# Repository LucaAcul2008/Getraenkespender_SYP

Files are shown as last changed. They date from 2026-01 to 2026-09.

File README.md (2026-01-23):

# Getraenkespender_SYP
Automatisierter IoT-Getränkemischer auf Basis eines ESP32 (MicroPython) mit modernem React-Frontend zur Konfiguration. Steuert 6-12V-Membranpumpen für präzise Mischverhältnisse.

# 🍹 Smart Drink Mixer (ESP32 + React)

Ein vollautomatischer Getränkemischer, der zwei Flüssigkeiten über Membranpumpen in einem definierten Verhältnis mischt. Das System wird über physische Taster bedient und über ein responsives Web-Interface konfiguriert.

Dieses Projekt entstand als Projektarbeit in SYP.

## 🚀 Funktionen
* **Duale Pumpensteuerung:** Unabhängige Ansteuerung von zwei 6-12V-Membranpumpen (Selbstansaugend).
* **Web-Konfiguration:** Modernes React-Frontend (Single Page Application) zum Erstellen und Speichern von Getränke-Rezepten.
* **Hardware-Bedienung:** 3 physische Taster zum direkten Auslösen der gespeicherten Mischprofile.
* **Persistenz:** Speicherung der Konfigurationen im Flash-Speicher des ESP32 (JSON).
* **Custom Gehäuse:** Hybrid-Gehäuse aus 3D-Druck-Komponenten und Holz.

## 🛠 Technologie-Stack

### Hardware
* **Controller:** ESP32 (WLAN integriert)
* **Aktorik:** 2x 6-12V DC Membranpumpen 
* **Treiber:** MOSFET Schaltung (Logic Level) zur Ansteuerung der 6-12V Pumpen über 3.3V GPIOs
* **Stromversorgung:** 12V Netzteil + Step-Down Converter (für ESP32)

### Software
* **Firmware (Backend):** MicroPython
    * REST-API für die Kommunikation mit dem Frontend
    * Dateisystem-Management für Config-Dateien
* **Frontend (UI):** React.js
    * Responsive Design (Mobile First)
    * Kommunikation via `fetch` API

## 📂 Projektstruktur
```text
/firmware      -> MicroPython Code für den ESP32 (main.py, boot.py)
/frontend      -> Quellcode der React Web-App
/3d-models     -> STL-Dateien für Halterungen und Gehäuse
/docs          -> Schaltpläne und Dokumentation

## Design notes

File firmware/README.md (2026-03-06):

# Firmware — MicroPython ESP32

## Flash Instructions

### Prerequisites

| Tool | How to install |
|---|---|
| MicroPython on ESP32 | [https://micropython.org/download/ESP32_GENERIC/](https://micropython.org/download/ESP32_GENERIC/) (v1.21+ recommended) |
| Node.js + npm | [https://nodejs.org](https://nodejs.org) |
| mpremote | `pip install mpremote` |

### Quick start — automated script (recommended)

Connect the ESP32 via USB, then run from the **repository root**:

```bash
chmod +x flash.sh
./flash.sh
```

This single command will:
1. Build the React frontend (`npm install` + `npm run build`)
2. Upload `boot.py`, `main.py`, `config.json` to the ESP32
3. Create the `/www` directory on the ESP32 and upload the built frontend
4. Restart the ESP32

After flashing, connect to the WiFi hotspot and open the app (see [WiFi](#wifi) below).

### Manual steps (alternative)

1. Build the frontend:
```bash
cd frontend/getraenkespender
npm install
npm run build
```
This produces `frontend/getraenkespender/www/`.

2. Upload firmware files (from the repository root):
```bash
mpremote cp firmware/boot.py   :boot.py
mpremote cp firmware/main.py   :main.py
mpremote cp firmware/config.json :config.json
```

3. Upload the built frontend:
```bash
mpremote mkdir :www
# Upload all files from the www/ build output
find frontend/getraenkespender/www -type f | while read f; do
    remote=":www${f#frontend/getraenkespender/www}"
    mpremote cp "$f" "$remote"
done
```

4. Restart the ESP32:
```bash
mpremote reset
```

## GPIO Pin Assignment

| Function | GPIO |
|---|---|
| Pump A | 16 |
| Pump B | 17 |
| Button 1 (Recipe 1) | 4 |
| Button 2 (Recipe 2) | 5 |
| Button 3 (Recipe 3) | 6 |

## WiFi

- **Mode:** Access Point
- **SSID:** `GetraenkeBot_3000`
- **Password:** `party1234`
- **ESP32 IP:** `192.168.4.1`
- **App URL:** `http://192.168.4.1`

## API Endpoints

| Method | Path | Description |
|---|---|---|
| GET | /api/status | Returns `{"status": "ready"}` or `{"status": "busy"}` |
| GET | /api/config | Returns full config JSON |
| POST | /api/config | Save new config JSON |
| POST | /api/action | Trigger an action (see below) |

### Actions (`POST /api/action` with `{"command": "..."}`)

| Command | Effect |
|---|---|
| `start_pump_A` | Pump A ON (manual) |
| `stop_pump_A` | Pump A OFF |
| `start_pump_B` | Pump B ON (manual) |
| `stop_pump_B` | Pump B OFF |
| `flush_all` | Both pumps 15s each |
| `recipe_1` | Run Recipe 1 |
| `recipe_2` | Run Recipe 2 |
| `recipe_3` | Run Recipe 3 |

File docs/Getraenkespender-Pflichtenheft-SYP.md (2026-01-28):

**Pflichtenheft**

| **Projektname** | Getränkespender |
| --- | --- |
| **Projektnummer** | |
| **Projektleiter** | Raphael Thaler |
| **Erstellt am** | 09.01.2026 |
| **Letzte Änderung am** | 16.01.2026 |
| **Status** | In Bearbeitung |
| **Aktuelle Version** | 1.1 |

**Änderungsverlauf**

| **Nr.** | **Datum** | **Version** | **Geänderte Kapitel** | **Art der Änderung** | **Autor** |
| --- | --- | --- | --- | --- | --- |
| 1 | 09.01.2026 | 1.0 | Alle | Erstellung | Luca Aigner |
| 2 | 16.01.2026 | 1.1 | 5.3, 5.4, 6.2 | Erweiterung | Luca Aigner |
| 3 | 27.01.2026 | 1.1 | 4.4, 5.3.2 | Erweiterung/Änderung | Luca Aigner |

Inhalt

[**1** **Einleitung** 4](#_Toc220435320)

[**2** **Allgemeines** 4](#_Toc220435321)

[2.1 **Ziel und Zweck des Dokuments** 4](#_Toc220435322)

[2.2 **Ausgangssituation** 4](#_Toc220435323)

[2.3 **Projektbezug** 4](#_Toc220435324)

[2.4 **Abkürzungen** 4](#_Toc220435325)

[2.5 **Teams und Schnittstellen** 4](#_Toc220435326)

[**3** **Konzept** 5](#_Toc220435327)

[3.1 **Ziel(e) des Anbieters** 5](#_Toc220435328)

[3.2 **Ziel(e) und Nutzen des Anwenders** 5](#_Toc220435329)

[3.3 **Zielgruppe(n)** 5](#_Toc220435330)

[3.3.1 **Endanwender (Konsumenten / Partygäste)** Diese Gruppe nutzt das Gerät ausschließlich zur Getränkeentnahme. 5](#_Toc220435331)

[3.3.2 **Betreiber (Gastgeber / Administratoren)** Diese Gruppe ist für die Inbetriebnahme, Befüllung und Konfiguration der Mischverhältnisse zuständig. 6](#_Toc220435332)

[3.3.3 **Privatanwender (Haushalt / Eigenbedarf)** Diese Zielgruppe stellt eine Personalunion aus Betreiber und Endanwender dar. Das Gerät wird im privaten Wohnbereich dauerhaft oder temporär aufgestellt. 6](#_Toc220435333)

[4 **Funktionale Anforderungen** 6](#_Toc220435334)

[4.1 **Kernfunktionalitäten (Hardware & Steuerung)** 6](#_Toc220435335)

[4.2 **Web-Interface & Konfiguration (React App)** 7](#_Toc220435336)

[4.3 **Datenhaltung & Kommunikation** 7](#_Toc220435337)

[4.4 **Optionale Erweiterung:** Gamification-Modul (Stochastisches Belohnungssystem) Dieses Modul dient der Erhöhung der Benutzerinteraktion durch einen spielerischen Ansatz ("Slot-Machine-Effekt"). 7](#_Toc220435338)

[**5** **Nichtfunktionale Anforderungen** 8](#_Toc220435339)

[5.1 **Allgemeine Anforderungen** 8](#_Toc220435340)

[5.2 **Gesetzliche Anforderungen** 8](#_Toc220435341)

[5.3 **Technische Anforderungen** 8](#_Toc220435342)

[5.3.1 **Web:** 8](#_Toc220435343)

[5.3.2 **Hardware:** 8](#_Toc220435344)

[5.4 **Betriebliche Anforderungen** 8](#_Toc220435345)

[6 Rahmenbedingungen 8](#_Toc220435346)

[6.1 Zeitplan 8](#_Toc220435347)

[_6.2_ **Rahmenbedingungen: Technische Anforderungen (Entwicklungsumgebung)** 8](#_Toc220435348)

[6.3 Problemanalyse 10](#_Toc220435349)

[6.4 Qualität 10](#_Toc220435350)

[7 Liefer- und Abnahmebedingungen 10](#_Toc220435351)

[8 Anhang 10](#_Toc220435352)

# **Einleitung**

Das vorliegende Pflichtenheft enthält die an das zu entwickelnde Produkt gestellten funktionalen sowie nicht-funktionalen Anforderungen. Es dient als Basis für die Ausschreibung und Vertragsgestaltung und bildet somit die Vorgabe für die Angebotserstellung. Kommt es zwischen Auftragnehmer und Auftraggeber zu einem Vertragsabschluss, ist das bestehende Pflichtenheft rechtlich bindend. Alle zuvor zwischen Auftraggeber und Auftragnehmer getroffenen Absprachen verlieren in der Regel durch das Pflichtenheft ihre Gültigkeit - sofern hier nichts Gegenteiliges vermerkt ist. Mit den Anforderungen werden die Rahmenbedingungen für die Entwicklung festgelegt, die vom Auftragnehmer im Pflichtenheft detailliert ausgestaltet werden.

# **Allgemeines**

## **Ziel und Zweck des Dokuments**

Dieses Pflichtenheft beschreibt ein Projekt über einen Getränkespender.

## **Ausgangssituation**

Dieses Projekt wird in schulischen Verhältnissen durchgeführt von Raphael Thaler, Luca Aigner, Lukas Gutmann und Clemens Deutinger.

## **Projektbezug**

Das vorliegende Projekt ist ein unabhängiges Projekt.

## **Abkürzungen**

_CT01 ist CodingTeam01_

_DT01 ist DesignTeam01_

_HWT01 ist HardwareTeam01_

## **Teams und Schnittstellen**

| **Rolle(n)** | **Name** | **Telefon** | **E-Mail** | **Team** |
| --- | --- | --- | --- | --- |
| Projektleiter | Raphael Thaler | 9116967 | [Raphael.thaler@htl-saalfelden.at](mailto:Raphael.thaler@htl-saalfelden.at) | CT01 |
| Entwickler | Luca Aigner | 06601442142 | [Luca.aigner@htl-saalfelden.at](mailto:Luca.aigner@htl-saalfelden.at) | CT01 |
| 3D-Designer | Clemens Deutinger | 06601411251 | [Clemens.deutinger@htl-saalfenden.at](mailto:Clemens.deutinger@htl-saalfenden.at) | DT01 |
| Systemelektroniker | Lukas Gutmann | 066704043305 | [Lukas.gutmann@htl-saalfelden.at](mailto:Lukas.gutmann@htl-saalfelden.at) | HWT01 |

Die Kommunikation erfolgt größtenteils von Person zu Person aber auch über Teams. Enge Zusammenarbeit besteht zwischen dem DT01 und HWT01 aber auch zwischen Kommunikationen mit CT01.

# **Konzept**

## **Ziel(e) des Anbieters**

Nachweis technischer Kompetenz (Proof of Concept): Es soll demonstriert werden, dass eine nahtlose Integration von Embedded Systems (ESP32/MicroPython) und modernen Web-Technologien (React) realisierbar ist. Ziel ist die Schaffung einer stabilen Kommunikationsschnittstelle (API) zwischen der Hardware-Steuerung und der Benutzeroberfläche.

Erstellung eines funktionsfähigen Prototyps (MVP): Ziel ist die Fertigstellung eines "Minimum Viable Product", das die Kernfunktionen (Pumpensteuerung, Konfiguration, Webserver) zuverlässig und reproduzierbar erfüllt. Der Prototyp soll als Basis für potenzielle spätere Erweiterungen (z.B. mehr Pumpen, Cloud-Anbindung) dienen.

Gewährleistung der Betriebssicherheit: Durch den Einsatz geeigneter Hardware-Komponenten (Gehäuse, MOSFET-Treiberstufen) und Software-Routinen soll ein sicherer Betrieb gewährleistet werden, bei dem Elektronik und Flüssigkeiten strikt getrennt sind, um Kurzschlüsse oder Fehlfunktionen zu vermeiden.

Benutzerfreundlichkeit (Usability) ohne Vorkenntnisse: Die einfache Bedienung mittels Knöpfe und eines Gefäßes. Die Funktion der Knöpfe werden mittels einem Papierlabel beschrieben.

## **Ziel(e) und Nutzen des Anwenders**

Gemütliche Zubereitung eines Mischgetränks durch einen Knopfdruck.

## **Zielgruppe(n)**

## **Endanwender (Konsumenten / Partygäste)** Diese Gruppe nutzt das Gerät ausschließlich zur Getränkeentnahme

**Charakteristika**: Technisch oft Laien; befinden sich in einem geselligen Umfeld (Party, Event); erwarten sofortige Ergebnisse ohne Einarbeitungszeit.

**Anforderungen an das Produkt:** Die Bedienung muss extrem simpel und selbsterklärend sein ("Walk-up-and-use"). Da diese Nutzer nur mit der Hardware (Gehäuse/Taster) interagieren, stehen Robustheit und klare Beschriftung (Papierschilder) im Vordergrund. Fehleingaben oder wildes Drücken der Tasten müssen softwareseitig abgefangen werden.  
<br/><br/><br/><br/>

## **Betreiber (Gastgeber / Administratoren)** Diese Gruppe ist für die Inbetriebnahme, Befüllung und Konfiguration der Mischverhältnisse zuständig

**Charakteristika:** Besitzen grundlegende Kenntnisse im Umgang mit Smartphones oder Laptops; sind verantwortlich für den reibungslosen Ablauf.

**Anforderungen an das Produkt:** Sie benötigen Zugriff auf die Konfigurationsebene (React-Webinterface). Für sie muss die Oberfläche übersichtlich gestaltet sein, um schnell Rezepte ändern zu können, ohne den Programmcode (MicroPython) verstehen oder bearbeiten zu müssen. Eine mobile Optimierung der Webseite ist für diese Gruppe essenziell, da die Konfiguration vermutlich spontan über das Smartphone erfolgt.

## **Privatanwender (Haushalt / Eigenbedarf)** Diese Zielgruppe stellt eine Personalunion aus Betreiber und Endanwender dar. Das Gerät wird im privaten Wohnbereich dauerhaft oder temporär aufgestellt

**Charakteristika:** Der Nutzer konfiguriert das Gerät nach seinen persönlichen Vorlieben und nutzt es anschließend selbst für den täglichen Bedarf oder im familiären Rahmen. Die Frequenz der Nutzung ist geringer als im Party-Betrieb, dafür erfolgt der Einsatz über einen längeren Zeitraum.

**Anforderungen an das Produkt:** Hier stehen **Komfort** und **Wartungsfreundlichkeit** im Fokus. Da der Nutzer auch für die Reinigung zuständig ist, muss der Prozess des Durchspülens oder Wechselns der Flüssigkeiten möglichst einfach gestaltet sein. Zudem spielen Ästhetik und Platzbedarf eine größere Rolle, da das Gerät in den Wohnraum integriert wird. Die Geräuschentwicklung der Pumpen sollte auf ein wohnraumtaugliches Maß beschränkt sein.

# **Funktionale Anforderungen**

## **Kernfunktionalitäten (Hardware & Steuerung)**

- **/F010/ Zeitgesteuerte Pumpenansteuerung:** Das System muss in der Lage sein, zwei Gleichstrompumpen (Pumpe A und Pumpe B) unabhängig voneinander ein- und auszuschalten. Die Ansteuerung erfolgt zeitbasiert (Dauer in Sekunden/Millisekunden).
- **/F020/ Mischprofile abrufen:** Das System muss auf dem Mikrocontroller (ESP32) drei vordefinierte Profile ("Rezepte") vorhalten. Ein Profil besteht aus einem Datensatz, der die Laufzeit für Pumpe A und Pumpe B definiert.
- **/F030/ Physische Auslösung (Trigger):** Über drei Hardware-Taster am Gehäuse muss der Mischvorgang gestartet werden können.
  - Taster 1 löst Profil 1 aus.
  - Taster 2 löst Profil 2 aus.
  - Taster 3 löst Profil 3 aus.
- **/F040/ Blockierfunktion (Interlock):** Während ein Pumpvorgang läuft, müssen Eingaben über die anderen Taster ignoriert werden, um eine Doppel-Dosierung oder Fehler im Ablauf zu verhindern.
- **/F050/ Not-Abbruch:** Es muss eine Möglichkeit geben, einen laufenden Pumpvorgang sofort zu beenden (z.B. durch langes Drücken eines beliebigen Tasters oder einen dedizierten Reset), falls ein Glas überläuft.

## **Web-Interface & Konfiguration (React App)**

- **/F060/ Dashboard-Ansicht:** Die Web-Applikation muss den aktuellen Status des Systems anzeigen (z.B. "Bereit", "Mischt gerade", "Fehler").
- **/F070/ Rezept-Konfiguration:** Die Webseite muss ein Formular bereitstellen, mit dem die Laufzeiten für Pumpe A und Pumpe B für jeden der drei Taster (Slots) individuell eingestellt werden können.
  - Eingabeformat: Numerisch (z.B. in Sekunden).
- **/F080/ Validierung:** Die Eingaben müssen vor dem Senden validiert werden (z.B. keine negativen Zeiten, maximale Laufzeitbegrenzung zum Schutz der Pumpen).
- **/F090/ Manuelle Steuerung (Wartungsmodus):** Über das Web-Interface sollen die Pumpen manuell gestartet und gestoppt werden können (z.B. zum Ansaugen der Flüssigkeit nach Neubefüllung oder zur Reinigung), ohne einen automatischen Timer zu nutzen.

## **Datenhaltung & Kommunikation**

- **/F100/ Persistente Speicherung:** Änderungen an den Rezepten, die über das Web-Interface vorgenommen werden, müssen dauerhaft im Flash-Speicher des ESP32 gespeichert werden (z.B. als JSON-Datei). Die Einstellungen müssen nach einem Stromausfall wiederhergestellt werden.
- **/F110/ API-Schnittstelle:** Der ESP32 muss eine REST-API (oder vergleichbare Schnittstelle) bereitstellen, über die das React-Frontend die aktuellen Konfigurationen lesen (GET) und neue Konfigurationen schreiben (POST) kann.

## **Optionale Erweiterung:** Gamification-Modul (Stochastisches Belohnungssystem)  

Dieses Modul dient der Erhöhung der Benutzerinteraktion durch einen spielerischen Ansatz ("Slot-Machine-Effekt").

- /F_OPT_010/ Signalverarbeitung Münzeinwurf: Das System muss digitale Impulse eines externen Münzprüfers (Coin Acceptor) erfassen. Ein valider Einwurf wird als "Trigger-Event" gewertet, der das System aus dem Ruhezustand weckt.
- /F_OPT_020/ Physische Interaktion (Hebel/Trigger): Der Spielmechanismus wird über einen physischen Aktor (Hebelmechanik mit Mikroschalter oder Arcade-Button) gestartet.
  - Sperre: Der Hebel ist standardmäßig softwareseitig deaktiviert. Betätigungen ohne vorherigen Münzeinwurf werden ignoriert (ggf. mit visueller Fehlermeldung).
  - Freigabe: Erst nach registriertem Münzeinwurf wird der Hebel für genau einen Spielzyklus freigegeben.
- /F_OPT_030/ Lokale Visualisierung (Display): Das Gerät verfügt über ein integriertes Display zur direkten Nutzerführung am Gerät, unabhängig vom Web-Interface.
  - Idle-State: Anzeige einer Aufforderung (z.B. "Münze einwerfen").
  - Game-State: Nach Betätigung des Hebels visualisiert das Display den Zufallsprozess (z.B. durchlaufende Symbole).
  - Result-State: Anzeige von "Gewinn" (Auslösen der Pumpen) oder "Niete".
- /F_OPT_040/ Zufallsalgorithmus (RNG): Der Mikrocontroller führt eine Zufallsberechnung durch. Die Gewinnwahrscheinlichkeit (z.B. 1:10) ist variabel.
- /F_OPT_050/ Admin-Konfiguration (Web): Die Konfiguration der Gewinnwahrscheinlichkeit und des ausgegebenen "Gewinn-Getränks" erfolgt ausschließlich über einen geschützten Bereich im React-Webinterface (Admin-Panel), auf den normale Endanwender keinen Zugriff haben.

# **Nichtfunktionale Anforderungen**

## **Allgemeine Anforderungen**

**/NF010/ Leistung & Reaktionszeit (Latenz)** Da das System physische Flüssigkeiten bewegt, ist die wahrgenommene Reaktionszeit entscheidend.

- **Pumpenstart:** Zwischen dem Drücken eines physischen Tasters und dem Anlaufen der Pumpen darf maximal eine Verzögerung von **3 Sekunden** liegen.
- **Web-Interface:** Da der ESP32 als Webserver begrenzte Ressourcen hat, wird eine Ladezeit der Konfigurations-Webseite von unter **8 Sekunden** angestrebt. Speicher-Operationen (Speichern der Config) müssen innerhalb von **5 Sekunde** bestätigt werden.  
    <br/><br/><br/><br/>

**/NF020/ Sicherheit (Safety & Security)**

- **Elektrische Sicherheit:** Da Elektronik und Flüssigkeiten (leitfähig) in einem Gerät verbaut sind, müssen die flüssigkeitsführenden Teile (Schläuche/Pumpen) physisch von der Steuerelektronik (ESP32/PCB) getrennt sein (z.B. durch eine Trennwand im 3D-Druck-Gehäuse).
- **Eingabevalidierung:** Die Software muss verhindern, dass fehlerhafte Eingaben (z.B. negative Zahlen oder Text statt Zahlen) im Web-Interface zu einem Absturz des Mikrocontrollers führen.
- **Spannung:** Das System arbeitet im für den Menschen ungefährlichen Kleinspannungsbereich (max. 12V DC).

**/NF030/ Portabilität & Kompatibilität (Web)**

- **Plattformunabhängigkeit:** Das Web-Interface (React) muss auf den gängigen Browsern (Chrome, Safari, Firefox) lauffähig sein.
- **Responsive Design:** Da die Konfiguration vorwiegend "nebenbei" erfolgt, muss das Interface zwingend für **mobile Endgeräte (Smartphones)** optimiert sein (Touch-Bedienung, skalierbare Layouts).

**/NF040/ Verfügbarkeit & Robustheit**

- **Wi-Fi Reconnect:** Bei Verlust der WLAN-Verbindung muss der ESP32 versuchen, die Verbindung selbstständig wiederherzustellen, ohne dass ein manueller Neustart erforderlich ist.
- **Stand-Alone Betrieb:** Die Kernfunktion (Getränkeausgabe über Taster) muss auch dann funktionieren, wenn keine WLAN-Verbindung besteht oder das Web-Interface gerade nicht aufgerufen wird.

**/NF050/ Wartbarkeit & Modularität**

- **Code-Trennung:** Die Software-Architektur muss eine klare Trennung zwischen Backend (MicroPython Steuerlogik) und Frontend (React UI) aufweisen.
- **Austauschbarkeit:** Das Gehäuse-Design muss so gestaltet sein, dass Verschleißteile (Schläuche, Pumpenköpfe) zu Reinigungszwecken ohne Zerstörung des Gehäuses entnommen werden können.

## **Gesetzliche Anforderungen**

**Compliance & Sicherheit (Lebensmittel & Elektrik)**

- **Lebensmittelkonformität (LFGB / EU 1935/2004):** Alle Bauteile, die in direkten Kontakt mit den Getränken kommen (Schläuche, Pumpenmechanik, Düsen), müssen als "lebensmittelecht" (food grade) zertifiziert sein oder aus entsprechenden Materialien (z.B. Silikon, PETG, Edelstahl) bestehen.

## **Technische Anforderungen**

## **Web:**

**Zielplattform (Client-Seite)** Da die Benutzeroberfläche als Web-Applikation realisiert wird, ist sie plattformunabhängig konzipiert. Die Unterstützung folgender Umgebungen muss gewährleistet sein:

- Betriebssysteme: Unabhängig (Windows, macOS, iOS, Android, Linux).
- Browser: Die Anwendung muss auf allen modernen, HTML5-fähigen Browsern lauffähig sein (Google Chrome, Mozilla Firefox, Apple Safari, Microsoft Edge). Die Unterstützung des veralteten Internet Explorers ist nicht vorgesehen.
- Mobile Endgeräte: Prioritäre Unterstützung von Smartphones und Tablets (iOS und Android) im Hochformat (Portrait-Mode), da dies das primäre Konfigurationswerkzeug für den "Betreiber" darstellt.

**Designvorgaben & User Interface (UI)**

- Mobile First & Responsive Design: Die React-Oberfläche muss sich dynamisch an die Bildschirmgröße anpassen. Auf kleinen Bildschirmen (Smartphones) werden Elemente untereinander angeordnet (Stacking), auf größeren Bildschirmen (Laptops) nebeneinander.
- Touch-Optimierung: Alle interaktiven Elemente (Buttons, Slider, Eingabefelder) müssen groß genug dimensioniert sein, um fehlerfrei mit dem Finger bedient werden zu können (Mindestgröße von Touch-Targets ca. 44x44 Pixel).
- Corporate Design / Styling: Das Design soll modern und minimalistisch gehalten werden. Es wird ein dunkles Farbschema ("Dark Mode") bevorzugt, da das Gerät voraussichtlich in abgedunkelten Umgebungen (Partys) eingesetzt wird und dies die Blendwirkung reduziert.

Barrierefreiheit (Accessibility) Die Software orientiert sich an grundlegenden Prinzipien der Barrierefreiheit, um die Bedienung auch unter erschwerten Bedingungen (schlechte Beleuchtung, eingeschränkte Motorik) zu ermöglichen:

- Skalierbarkeit: Texte müssen über die Browser-Einstellungen vergrößerbar sein, ohne das Layout zu zerstören.
- Kontraste: Es ist auf einen ausreichenden Kontrast zwischen Text und Hintergrund zu achten, um die Lesbarkeit in dunklen Räumen zu gewährleisten.
- Visuelles Feedback: Interaktionen (z.B. Speichern der Konfiguration) müssen durch eindeutige visuelle Rückmeldungen (Ladebalken, Farbwechsel, "Toast"-Nachrichten) bestätigt werden, damit der Nutzer nicht auf Audio-Feedback angewiesen ist.

## **Hardware:**

**Recheneinheit (Mikrocontroller)**

- **Komponente:** ESP32 SoC (System on a Chip).
- **Anforderung:** Der Controller muss über integriertes WLAN (2.4 GHz) verfügen, um den Webserver bereitstellen zu können.
- **Speicher:** Ausreichend Flash-Speicher (min. 4MB) für die MicroPython-Firmware, die React-Web-Applikation und die Konfigurationsdateien.
- **I/O-Schnittstellen:** Es werden mindestens 5 GPIOs benötigt (2x Output für Pumpen, 3x Input für Taster).

**Aktorik & Fluidik**

- **Pumpen:** Einsatz von zwei selbstansaugenden Membranpumpen (6V-12V).
  - _Anforderung:_ Die Pumpen müssen lebensmittelecht sein und eine Saughöhe aufweisen, die es erlaubt, Flüssigkeiten aus unterhalb stehenden Behältern zu fördern (Self-priming).
- **Leistungselektronik (Treiberstufe):**
  - Da der Mikrocontroller (3.3V) die Pumpen (6V) nicht direkt treiben kann, ist eine Treiberstufe erforderlich.
  - _Anforderung:_ Einsatz von MOSFETs (z.B. IRLZ44N oder Module), um die galvanische Trennung und Leistungsverstärkung sicherzustellen.

**Stromversorgung**

- **Spannungsquelle:** Externes Netzteil (9V DC), welches genügend Strom (min. 2A) liefert, um beide Pumpen simultan sowie den Controller zu versorgen.
- **Spannungswandlung:** Integration eines Step-Down-Converters (Buck Converter) zur effizienten Wandlung von 9V auf 5V/3.3V für den ESP32.
- **Spannungswandlung (Peripherie):** Falls Komponenten mit 12V-Bedarf (z.B. Standard-Münzprüfer) eingesetzt werden, ist der Einsatz eines Step-Up-Converters (Boost Converter) von 9V auf 12V vorzusehen.

**Gehäuse & Physischer Aufbau**

- **Material:** Hybrid-Konstruktion aus 3D-Druck-Komponenten (für Halterungen und Passgenauigkeit) und Holz (für die Struktur/Optik).
- **Zwei-Kammer-System:** Konstruktive Trennung in einen "Nassbereich" (Schläuche, Auslassdüse) und einen "Trockenbereich" (ESP32, Netzteil, MOSFETs), um die Elektronik vor Leckagen zu schützen.

**Zusatz-Peripherie (Gamification)**

- **Display-Einheit:** OLED (z.B. SH1106/SSD1306) oder TFT Modul zur Statusanzeige direkt am Gehäuse.
- **Eingabe-Sensorik:** Mikroschalter (Microswitch) zur Erfassung der Hebel-Position (mechanischer Trigger).
- **Münzverarbeitung:** Elektronischer Münzprüfer mit 12V Puls-Signal.
  - **Interface:** Anbindung an den ESP32 über Pegelwandler oder Spannungsteiler (Level Shifter), um das 12V Signal auf verträgliche 3.3V zu skalieren.

## **Betriebliche Anforderungen**

**Deployment-Prozess (Software-Verteilung)** Da das System lokal und ohne Internetanbindung arbeitet, erfolgt das Deployment neuer Software-Versionen nicht über eine Cloud-Pipeline (CI/CD), sondern physisch am Gerät.

- **Firmware-Flash:** Das Aufspielen der MicroPython-Firmware und des React-Frontends (Build-Dateien) erfolgt über eine kabelgebundene USB-Verbindung (Serielle Schnittstelle) mittels geeigneter Tools (z.B. Thonny IDE, esptool).
- **Build-Pipeline:** Die React-Applikation muss vor dem Deployment lokal auf einem Entwickler-PC kompiliert ("build") und minifiziert werden, um den begrenzten Speicherplatz des ESP32 nicht zu überlasten.

**Hosting und Infrastruktur (On-Device Hosting)**

- **Self-Hosted:** Das System agiert vollständig autark ("On-Premises" / "On-Device"). Der ESP32 übernimmt die Rolle des Webservers und des Datenbank-Servers (Dateisystem). Es ist keine externe Server-Infrastruktur oder Cloud-Anbindung (AWS/Azure) erforderlich.
- **Netzwerk-Infrastruktur:** Das Gerät spannt entweder einen eigenen WLAN-Access-Point (AP-Mode) auf oder integriert sich in ein bestehendes lokales WLAN (Station-Mode).

**Backup und Wiederherstellung (Disaster Recovery)**

- **Konfigurations-Sicherheit:** Die vom Benutzer erstellten Rezepte (in der config.json) verbleiben im Flash-Speicher. Es ist kein automatisches Cloud-Backup vorgesehen.
- **Factory Reset:** Für den Fall einer fehlerhaften Konfiguration (z.B. WLAN-Passwort falsch eingegeben oder Endlosschleife im Code) muss eine Möglichkeit bestehen, das Gerät auf die Werkseinstellungen zurückzusetzen (z.B. durch Neu-Flashen via USB).
- **Quellcode-Sicherung:** Der Entwicklungsstand (Source Code) wird über ein Versionsverwaltungssystem (z.B. Git/GitHub) gesichert, um bei Datenverlust auf dem Entwickler-PC den Code wiederherstellen zu können.

**Wartung und Pflege (Maintenance)**

- **Software-Wartung:** Fehlerbehebungen (Bugfixes) oder Funktionserweiterungen erfordern den physischen Zugriff auf das Gerät (USB-Anschluss).
- **Hardware-Wartung (Hygiene):** Aufgrund des Lebensmittelkontakts müssen regelmäßige Wartungsintervalle für die Reinigung definiert werden (Durchspülen des Systems mit Wasser/Reinigungsmittel). Das System muss hierfür einen softwaregestützten Wartungsmodus ("Reinigungszyklus") bereitstellen, der beide Pumpen dauerhaft aktiviert.

# Rahmenbedingungen

_Hier gehen Sie zum Beispiel auf die gesamte Bearbeitungszeit ein. Beschreiben Sie ruhig auch die geplanten Betriebs- und Arbeitszeiten._

_Wird das Projekt nach einem bestimmen Entwicklungsprozess durchgeführt? (z.B.: V-modell, Wasserfallmodel, Agile, ...)_

## Zeitplan

_Wie viel Zeit wird für einzelne Phasen voraussichtlich aufgwendet? Hier sollte eine Übersicht folgen, die möglichst auch Arbeitszeiten oder ggf. Betriebspausen miteinbezieht._

## **Rahmenbedingungen: Technische Anforderungen (Entwicklungsumgebung)**

Für die Realisierung des Projekts werden folgende Technologien, Software-Stacks und Entwicklungswerkzeuge eingesetzt:

**Programmiersprachen und Technologien**

- **Frontend (Benutzeroberfläche):**
  - **Framework:** React.js (JavaScript/JSX) zur Erstellung einer dynamischen Single-Page-Application (SPA).
  - **Styling:** CSS3 (ggf. mit CSS-Frameworks oder Modulen) für das responsive Design.
  - **Build-Prozess:** Nutzung von Node.js und npm (Node Package Manager), um den React-Code in statische HTML/JS-Dateien zu kompilieren, die auf dem Mikrocontroller gehostet werden können.
- **Backend / Firmware (Steuerung):**
  - **Sprache:** MicroPython. Diese Sprache wurde gewählt, da sie eine schnelle Iteration ermöglicht und leistungsfähige Bibliotheken für die Hardware-Ansteuerung (GPIO, WLAN) sowie einfache Webserver-Funktionalitäten bietet.
  - **Kommunikation:** Datenaustausch zwischen Frontend und Backend erfolgt über **HTTP-Requests (REST-API)** im JSON-Format.

**Datenbankanforderungen (Datenhaltung)**

- **File-Based Storage:** Aufgrund der Ressourcenbeschränkung des ESP32 wird keine relationale Datenbank (wie MySQL) eingesetzt.
- **Format:** Die Speicherung der Konfigurationen (Rezepte, Pumpenlaufzeiten) erfolgt in strukturierten **JSON-Dateien** (config.json) direkt im nicht-flüchtigen Flash-Dateisystem (LittleFS/FAT) des ESP32.
- **Anforderung:** Das Dateisystem muss so implementiert sein, dass Lese- und Schreibzugriffe threadsicher erfolgen, um Datenkorruption bei gleichzeitigen Zugriffen (Web-Request vs. Taster-Druck) zu vermeiden.

**Systemintegration (Schnittstellen)**

- **Hardware-Integration:** Der ESP32 steuert die Peripherie nicht direkt, sondern über eine definierte GPIO-Schnittstelle.
  - _Ausgänge:_ PWM- oder Digitalsignale an die Gate-Treiber (MOSFETs) der Pumpen.
  - _Eingänge:_ Digitale Inputs mit Pull-Up-Widerständen für die Taster.
- **Netzwerk-Integration:** Das System integriert sich als Client in ein bestehendes WLAN (Station Mode) oder fungiert als Access Point. Es werden keine externen APIs (Wetterdaten, Social Media) eingebunden.

**Entwicklungsumgebung & Tools**

- **Code-Editoren (IDEs):**
  - **Visual Studio Code:** Hauptentwicklungsumgebung für die React-Webapplikation und Code-Verwaltung.
  - **Visual Studio Code / Pymakr Plugin & Python Plugin:** Zum Flashen der Firmware, Hochladen der Dateien auf den ESP32 und zum Debugging (REPL-Konsole).
- **Versionskontrolle:**
  - **Git & GitHub:** Zur Versionierung des Quellcodes und zur Zusammenarbeit im Team. Es werden separate Repositories oder Ordner für Frontend und Firmware geführt.
- **Schaltplan & Design:**
  - **Fritzing:** Zur Erstellung der Schaltpläne und Verkabelungsskizzen.
  - **CAD-Software (CREO):** Für das Design des 3D-gedruckten Gehäuses und der Pumpenhalterungen

## Problemanalyse

_Fassen Sie die wichtigsten Probleme zusammen, die Sie erwarten. Wichtig ist vor allem, dass Sie für die wahrscheinlichsten Probleme bereits einen Lösungsansatz formulieren, um später Zeit zu sparen. Machen Sie sich auch über unwahrscheinliche Probleme Gedanken._

## Qualität

_Welche Anforderungen stellen Sie an die Qualität? Beschreiben Sie auch, wie die Qualitätssicherung, -kontrolle und -abnahme aussieht._

z.B.:

_·_ **_Testanforderungen_**_: Vorgaben zu Unit-Tests, Integrationstests, Lasttests und Benutzerakzeptanztests._

_·_ **_Fehlerbehandlung_**_: Beschreibung der Anforderungen an die Protokollierung und den Umgang mit Fehlern (z.B. Logging, Benutzerwarnungen)._

_·_ **_Code-Standards_**_: Einhaltung von Coding Guidelines, Best Practices und Überprüfung des Codes durch Code Reviews._

# Liefer- und Abnahmebedingungen

_Hier wird festgehalten, in welchem Umfang und zu welchem Preis Sie an Ihren Kunden wann und wo liefern sollen._

_Witerhin wird hier spezifiziert, wann das Projekt als abgeschlossen gilt und wer definiert, ob die Qualität stimmt. Es sollte klar festgelegt werden, wer für die Abnahme verantwortlich ist._

# Anhang

_Alle weiteren Dokumente oder Zahlen und Fakten, die als Hintergrund zu dem Projekt dienen._

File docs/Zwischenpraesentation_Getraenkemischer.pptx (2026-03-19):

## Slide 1

GETRÄNKEMISCHER

Zwischenpräsentation — Projektstand März 2026

Projektteam

Raphael Thaler (PL)
Luca Aigner · Lukas Gutmann · Clemens Deutinger

HTL Saalfelden · SYP 2025/26

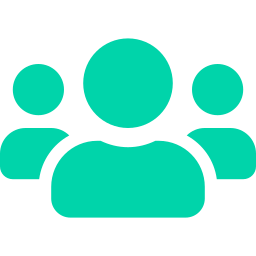
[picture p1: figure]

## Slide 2

AGENDA

Projektuebersicht

Was bauen wir?

01

Aktueller Projektstand

Was funktioniert bereits?

02

Verzögerungen & Risiken

Wo gibt es Probleme?

03

Meilensteintrendanalyse

Visualisierung der Trends

04

Nächste Schritte

Wie geht es weiter?

05

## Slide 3

PROJEKTÜBERSICHT

Was ist der Getränkemischer?

Ein automatisierter Getränkespender mit ESP32-Mikrocontroller, zwei Pumpen und einer React-Weboberfläche zur Konfiguration.

3 konfigurierbare Mischprofile

Physische Taster + Web-Interface

REST-API zwischen Frontend & ESP32

Dark-Mode UI, Mobile-First Design

Frontend

React.js + TypeScript + Vite

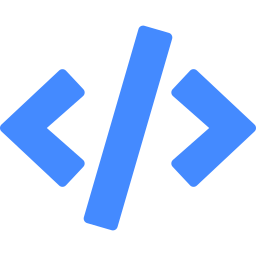
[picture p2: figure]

Backend

MicroPython auf ESP32

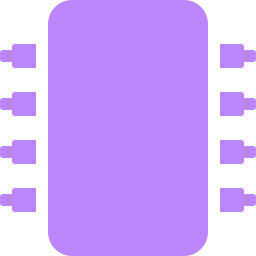
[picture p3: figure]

Hardware

3D-Druck + Holzgehäuse + Pumpen

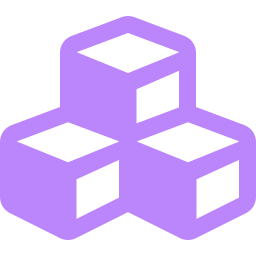
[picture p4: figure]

Kommunikation

REST-API (JSON über HTTP)

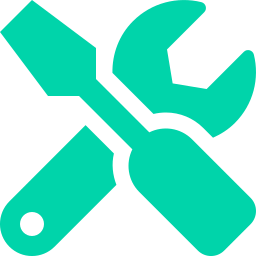
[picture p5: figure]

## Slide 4

AKTUELLER PROJEKTSTAND

Frontend (React)

Fertig

Login, Dashboard, Konfiguration, Navigation

Backend (ESP32)

Fertig

API, Pumpensteuerung, Webserver, Config

100%

100%

Designphase (CAD)

Verzögert

CAD-Design & 3D-Druck in Verzug

60%

Gehäusemontage

Verzögert

Abhängig von Designphase, Montage offen

40%

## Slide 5

VERZÖGERUNGEN & RISIKEN

Designphase (CAD & 3D-Druck)

Plan: 27.02.2026 → Aktuell: ca. 27.03.2026 (+4 Wochen)
Ursache: CAD-Modellierung komplexer als erwartet, 3D-Druck-Iterationen nötig
Auswirkung: Gehäusemontage und finaler Zusammenbau verzögern sich

KRITISCH

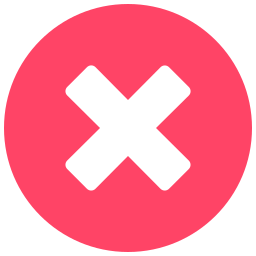
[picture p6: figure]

Gehäusemontage

Plan: 27.03.2026 → Aktuell: ca. 08.04.2026 (+12 Tage)
Blockiert durch Designphase — Montage kann erst nach Fertigstellung der 3D-Teile starten

WARNUNG

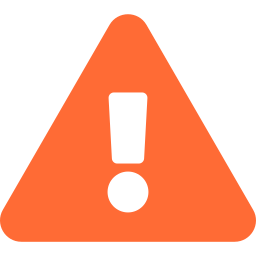
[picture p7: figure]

Frontend & Backend vorplanmäßig fertig — Software-Seite kein Risiko

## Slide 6

MEILENSTEINTRENDANALYSE

Trend der Meilenstein-Termine über die Berichtszeitraeume

Meilenstein | Plan | Aktuell | Delta | Trend
Designphase abgeschlossen | 27.02. | 27.03. | +4 Wochen | ↗ steigend
HW & Gehäuse montiert | 27.03. | 08.04. | +12 Tage | ↗ steigend
Backend & Elektronik | 10.04. | 27.03. | –2 Wochen | ↘ fallend
Frontend steuert HW | 17.04. | 20.03. | –4 Wochen | ↘ fallend
MVP funktionsfähig | 29.05. | 29.05. | ±0 | → stabil

Die Software-Meilensteine wurden vorzeitig erreicht und kompensieren teilweise die Hardware-Verzögerungen. Der MVP-Termin (29.05.) bleibt realistisch.

Interpretation:

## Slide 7

NÄCHSTE SCHRITTE

1

Designphase abschliessen

KW 13

CAD-Modelle finalisieren, 3D-Druck abschließen

Clemens (DT01)

2

Gehäusemontage & Verkabelung

KW 14–15

Gehäuse zusammenbauen, Elektronik integrieren

Lukas (HWT01)

3

Funktionstest (Trocken)

Software-Hardware-Integration prüfen

Luca + Raphael

KW 15

4

Wassertest & Kalibrierung

Dichtheit, Pumpen-Timing, Mengenmessung

Gesamtes Team

KW 16–20

5

Abschlusspraesentation

KW 25

Vorbereitung und Präsentation des fertigen MVP

Raphael (PL)

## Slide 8

DANKE!

Fragen & Diskussion

Raphael Thaler (PL) — raphael.thaler@htl-saalfelden.at
Luca Aigner — luca.aigner@htl-saalfelden.at
Lukas Gutmann — lukas.gutmann@htl-saalfelden.at
Clemens Deutinger — clemens.deutinger@htl-saalfelden.at

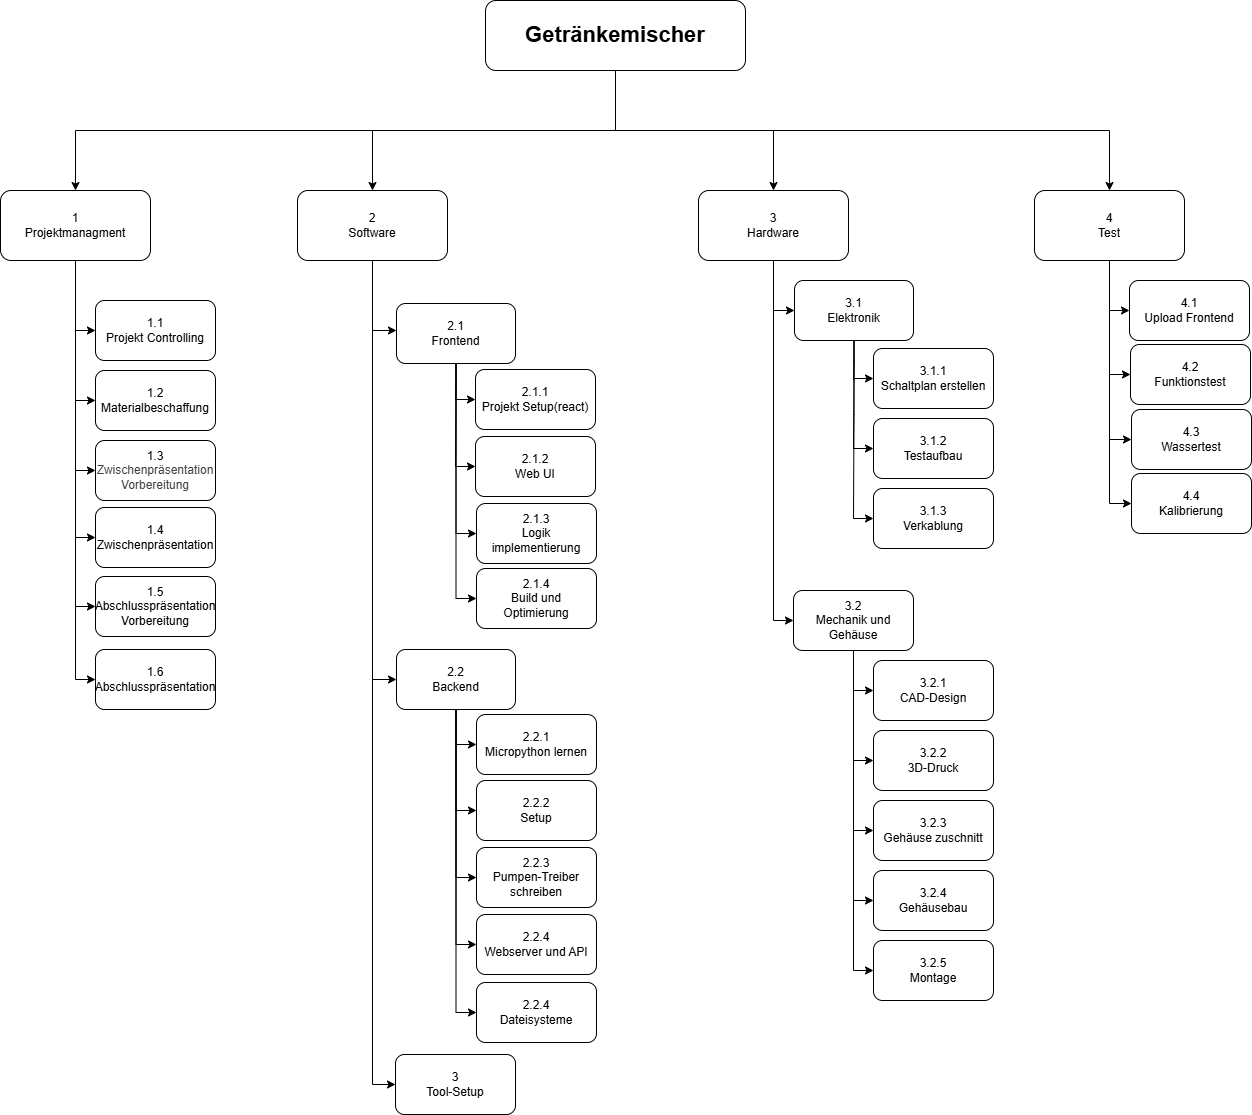
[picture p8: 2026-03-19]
docs/PSP_Syp 1.png

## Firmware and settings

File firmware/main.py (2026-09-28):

# firmware/main.py
import ujson
import uos
import machine
import time
import socket
import _thread

# --- Pin Setup ---
PUMP_A_PIN = machine.Pin(32, machine.Pin.OUT)
PUMP_B_PIN = machine.Pin(33, machine.Pin.OUT)
BTN_1_PIN  = machine.Pin(25, machine.Pin.IN, machine.Pin.PULL_UP)
BTN_2_PIN  = machine.Pin(26, machine.Pin.IN, machine.Pin.PULL_UP)
BTN_3_PIN  = machine.Pin(27, machine.Pin.IN, machine.Pin.PULL_UP)
LED_1_PIN  = machine.Pin(13, machine.Pin.OUT)
LED_2_PIN  = machine.Pin(16, machine.Pin.OUT)
LED_3_PIN  = machine.Pin(17, machine.Pin.OUT)

PUMP_A_PIN.value(0)
PUMP_B_PIN.value(0)
LED_1_PIN.value(0)
LED_2_PIN.value(0)
LED_3_PIN.value(0)

CONFIG_FILE = 'config.json'
is_busy      = False
emergency_stop = False
CONFIG_RELOAD_INTERVAL = 200

LEDS = [LED_1_PIN, LED_2_PIN, LED_3_PIN]

# --- Config Helpers ---
def load_config():
    try:
        with open(CONFIG_FILE, 'r') as f:
            return ujson.load(f)
    except:
        return {
            "recipes": [
                {"id": 1, "name": "Rezept 1", "pumpA": 5.0, "pumpB": 2.0},
                {"id": 2, "name": "Rezept 2", "pumpA": 3.0, "pumpB": 3.0},
                {"id": 3, "name": "Wasser",   "pumpA": 0.0, "pumpB": 5.0}
            ],
            "slotMachineChance": 10,
            "calibrationFactor": 5.0,
            "bottleA_ml": 1500,
            "bottleB_ml": 1500,
            "remainingA_ml": 1500,
            "remainingB_ml": 1500
        }

def save_config(cfg):
    with open(CONFIG_FILE, 'w') as f:
        ujson.dump(cfg, f)

def deduct_volume(pump_a_sec, pump_b_sec):
    cfg = load_config()
    cal = cfg.get('calibrationFactor', 5.0)
    ml_per_sec = 100.0 / cal if cal > 0 else 0
    cfg['remainingA_ml'] = max(0, cfg.get('remainingA_ml', 0) - pump_a_sec * ml_per_sec)
    cfg['remainingB_ml'] = max(0, cfg.get('remainingB_ml', 0) - pump_b_sec * ml_per_sec)
    save_config(cfg)
    return cfg['remainingA_ml'], cfg['remainingB_ml']

def is_bottle_empty(pump_a_sec, pump_b_sec):
    cfg = load_config()
    cal = cfg.get('calibrationFactor', 5.0)
    ml_per_sec = 100.0 / cal if cal > 0 else 0
    needed_a = pump_a_sec * ml_per_sec
    needed_b = pump_b_sec * ml_per_sec
    rem_a = cfg.get('remainingA_ml', 0)
    rem_b = cfg.get('remainingB_ml', 0)
    
    if pump_a_sec > 0 and rem_a < needed_a: return True, 'A'
    if pump_b_sec > 0 and rem_b < needed_b: return True, 'B'
    return False, None

# --- LED Helpers ---
def set_leds(a, b, c):
    LED_1_PIN.value(a)
    LED_2_PIN.value(b)
    LED_3_PIN.value(c)

def all_leds_off():
    set_leds(0, 0, 0)

def blink_all_leds_async(stop_flag):
    while not stop_flag[0]:
        set_leds(1, 1, 1)
        time.sleep(0.4)
        all_leds_off()
        time.sleep(0.4)
    all_leds_off()

# --- Pump Control ---
def emergency_stop_all():
    global is_busy, emergency_stop
    PUMP_A_PIN.value(0)
    PUMP_B_PIN.value(0)
    emergency_stop = True
    is_busy = False
    for _ in range(5):
        set_leds(1, 1, 1)
        time.sleep(0.1)
        all_leds_off()
        time.sleep(0.1)

def run_recipe(pump_a_sec, pump_b_sec, active_btn_led=None):
    global is_busy, emergency_stop
    if is_busy: return

    empty, _ = is_bottle_empty(pump_a_sec, pump_b_sec)
    if empty:
        for _ in range(10):
            set_leds(1, 1, 1)
            time.sleep(0.25)
            all_leds_off()
            time.sleep(0.25)
        return

    is_busy = True
    emergency_stop = False
    last_blink = time.ticks_ms()
    blink_on = False

    try:
        start = time.ticks_ms()
        if pump_a_sec > 0: PUMP_A_PIN.value(1)
        if pump_b_sec > 0: PUMP_B_PIN.value(1)

        a_done = pump_a_sec <= 0
        b_done = pump_b_sec <= 0

        while not (a_done and b_done):
            if emergency_stop: break
            elapsed = time.ticks_diff(time.ticks_ms(), start) / 1000.0
            if not a_done and elapsed >= pump_a_sec:
                PUMP_A_PIN.value(0)
                a_done = True
            if not b_done and elapsed >= pump_b_sec:
                PUMP_B_PIN.value(0)
                b_done = True
            if active_btn_led is not None:
                now = time.ticks_ms()
                if time.ticks_diff(now, last_blink) >= 300:
                    blink_on = not blink_on
                    active_btn_led.value(1 if blink_on else 0)
                    last_blink = now
            time.sleep(0.05)

        if not emergency_stop:
            deduct_volume(pump_a_sec, pump_b_sec)
            if active_btn_led is not None:
                active_btn_led.value(1)
                time.sleep(0.5)
    finally:
        PUMP_A_PIN.value(0)
        PUMP_B_PIN.value(0)
        if active_btn_led is not None:
            active_btn_led.value(0)
        is_busy = False

def run_recipe_async(pump_a_sec, pump_b_sec, active_btn_led=None):
    _thread.start_new_thread(run_recipe, (pump_a_sec, pump_b_sec, active_btn_led))

def run_flush():
    global is_busy, emergency_stop
    if is_busy: return
    is_busy = True
    emergency_stop = False
    try:
        start = time.ticks_ms()
        PUMP_A_PIN.value(1)
        PUMP_B_PIN.value(1)
        while time.ticks_diff(time.ticks_ms(), start) < 15000:
            if emergency_stop: break
            set_leds(1, 1, 1)
            time.sleep(0.3)
            all_leds_off()
            time.sleep(0.3)
    finally:
        PUMP_A_PIN.value(0)
        PUMP_B_PIN.value(0)
        all_leds_off()
        is_busy = False

# --- HTTP Server & Routing ---
CORS_HEADERS = 'Access-Control-Allow-Origin: *\r\nAccess-Control-Allow-Methods: GET, POST, OPTIONS\r\nAccess-Control-Allow-Headers: Content-Type\r\n'

def send_json(conn, data, status=200):
    body = ujson.dumps(data).encode()
    conn.send('HTTP/1.1 {} OK\r\nContent-Type: application/json\r\n{}Content-Length: {}\r\n\r\n'.format(
        status, CORS_HEADERS, len(body)).encode())
    conn.send(body)

def send_options(conn):
    conn.send('HTTP/1.1 204 No Content\r\n{}\r\n'.format(CORS_HEADERS).encode())

def read_body(request_text):
    try:
        parts = request_text.split('\r\n\r\n', 1)
        if len(parts) > 1: return parts[1].strip()
    except: pass
    return ''

def serve_file(conn, path):
    try:
        size = uos.stat(path)[6]
        ext = path.split('.')[-1]
        mime = {'html': 'text/html', 'js': 'application/javascript', 'css': 'text/css',
                'json': 'application/json', 'svg': 'image/svg+xml', 'ico': 'image/x-icon'}.get(ext, 'application/octet-stream')
        conn.send('HTTP/1.1 200 OK\r\nContent-Type: {}\r\nContent-Length: {}\r\n\r\n'.format(mime, size).encode())
        with open(path, 'rb') as f:
            while True:
                chunk = f.read(1024)
                if not chunk:
                    break
                conn.send(chunk)
    except OSError:
        conn.send(b'HTTP/1.1 404 Not Found\r\n\r\n404 Not Found')

def handle_request(conn):
    global is_busy, emergency_stop
    try:
        request = conn.recv(8192).decode('utf-8', 'ignore')
        lines = request.split('\r\n')
        if not lines or len(lines[0]) < 3: return
        
        method, path_full, *_ = lines[0].split(' ') + ['', '']
        path = path_full.split('?')[0]

        if method == 'OPTIONS':
            send_options(conn)
            return

        if path == '/api/status':
            cfg = load_config()
            send_json(conn, {
                'status': 'busy' if is_busy else 'ready',
                'remainingA_ml': cfg.get('remainingA_ml', 0),
                'remainingB_ml': cfg.get('remainingB_ml', 0),
                'bottleA_ml': cfg.get('bottleA_ml', 1500),
                'bottleB_ml': cfg.get('bottleB_ml', 1500)
            })

        elif path == '/api/config':
            if method == 'GET':
                send_json(conn, load_config())
            elif method == 'POST':
                body = read_body(request)
                try:
                    new_cfg = ujson.loads(body)
                    save_config(new_cfg)
                    send_json(conn, {'ok': True})
                except Exception as e:
                    send_json(conn, {'error': str(e)}, 400)

        elif path == '/api/refill':
            if method == 'POST':
                body = read_body(request)
                try:
                    data = ujson.loads(body)
                    cfg = load_config()
                    pump = data.get('pump', 'both')
                    if pump in ('A', 'both'): cfg['remainingA_ml'] = cfg.get('bottleA_ml', 1500)
                    if pump in ('B', 'both'): cfg['remainingB_ml'] = cfg.get('bottleB_ml', 1500)
                    save_config(cfg)
                    send_json(conn, {'ok': True, 'remainingA_ml': cfg['remainingA_ml'], 'remainingB_ml': cfg['remainingB_ml']})
                except Exception as e:
                    send_json(conn, {'error': str(e)}, 400)

        elif path == '/api/action':
            if method == 'POST':
                body = read_body(request)
                try:
                    data = ujson.loads(body)
                    cmd = data.get('command', '')
                except: cmd = ''

                if cmd == 'emergency_stop':
                    emergency_stop_all()
                    send_json(conn, {'ok': True})
                elif cmd == 'start_pump_A':
                    PUMP_A_PIN.value(1)
                    send_json(conn, {'ok': True})
                elif cmd == 'stop_pump_A':
                    PUMP_A_PIN.value(0)
                    send_json(conn, {'ok': True})
                elif cmd == 'start_pump_B':
                    PUMP_B_PIN.value(1)
                    send_json(conn, {'ok': True})
                elif cmd == 'stop_pump_B':
                    PUMP_B_PIN.value(0)
                    send_json(conn, {'ok': True})
                elif cmd == 'flush_all':
                    if not is_busy:
                        _thread.start_new_thread(run_flush, ())
                        send_json(conn, {'ok': True})
                    else:
                        send_json(conn, {'error': 'busy'}, 409)
                elif cmd.startswith('recipe_'):
                    try:
                        recipe_id = int(cmd.split('_')[1])
                        cfg = load_config()
                        recipe = next((r for r in cfg['recipes'] if r['id'] == recipe_id), None)
                        led = LEDS[recipe_id - 1] if 1 <= recipe_id <= 3 else None
                        if recipe and not is_busy:
                            run_recipe_async(recipe['pumpA'], recipe['pumpB'], led)
                            send_json(conn, {'ok': True})
                        elif is_busy:
                            send_json(conn, {'error': 'busy'}, 409)
                        else:
                            send_json(conn, {'error': 'recipe not found'}, 404)
                    except Exception as e:
                        send_json(conn, {'error': str(e)}, 400)
                else:
                    send_json(conn, {'error': 'unknown command'}, 400)

        elif path == '/' or path == '/index.html':
            serve_file(conn, '/www/index.html')
        else:
            serve_file(conn, '/www' + path)

    except Exception as e:
        print('Request error:', e)
    finally:
        conn.close()

def start_server():
    addr = socket.getaddrinfo('0.0.0.0', 80)[0][-1]
    s = socket.socket()
    s.setsockopt(socket.SOL_SOCKET, socket.SO_REUSEADDR, 1)
    s.bind(addr)
    s.listen(5)
    print('HTTP server running on port 80')
    while True:
        try:
            conn, addr = s.accept()
            handle_request(conn)
        except Exception as e:
            print('Server error:', e)

# --- Physical Button Polling ---
def poll_buttons():
    global is_busy, emergency_stop
    last_states   = [1, 1, 1]
    press_times   = [0, 0, 0]  
    btn1_tap_times = []        
    buttons = [BTN_1_PIN, BTN_2_PIN, BTN_3_PIN]
    leds    = [LED_1_PIN, LED_2_PIN, LED_3_PIN]
    cfg = load_config()
    cfg_reload_counter = 0

    while True:
        cfg_reload_counter += 1
        if cfg_reload_counter > CONFIG_RELOAD_INTERVAL:
            cfg = load_config()
            cfg_reload_counter = 0

        now = time.ticks_ms()
        states = [btn.value() for btn in buttons]

        # 3 Knöpfe gleichzeitig (Spülung - 5 Sek)
        if states[0] == 0 and states[1] == 0 and states[2] == 0:
            if press_times[2] == 0: press_times[2] = now
            elif time.ticks_diff(now, press_times[2]) >= 5000:
                print('Spuelung!')
                if not is_busy: _thread.start_new_thread(run_flush, ())
                press_times[2] = 0
                time.sleep(1) # Entprellen nach Aktion
        # 2 Knöpfe gleichzeitig (Not-Aus - 2 Sek)
        elif (states[0] == 0 and states[1] == 0) or (states[1] == 0 and states[2] == 0) or (states[0] == 0 and states[2] == 0):
            press_times[2] = 0 # Reset 3-Knopf counter
            if press_times[0] == 0: press_times[0] = now
            elif time.ticks_diff(now, press_times[0]) >= 2000:
                print('NOT-AUS!')
                emergency_stop_all()
                press_times[0] = 0
                time.sleep(1)
        else:
            press_times[0] = 0
            press_times[2] = 0

            # Einzelne Knöpfe prüfen
            for i, _ in enumerate(buttons):
                state = states[i]
                if state == 0 and last_states[i] == 1: 
                    print('Button {} pressed'.format(i + 1))

                    if i == 0:
                        btn1_tap_times.append(now)
                        btn1_tap_times = [t for t in btn1_tap_times if time.ticks_diff(now, t) < 2000]
                        if len(btn1_tap_times) >= 3:
                            print('Refill bestätigt!')
                            cfg['remainingA_ml'] = cfg.get('bottleA_ml', 1500)
                            cfg['remainingB_ml'] = cfg.get('bottleB_ml', 1500)
                            save_config(cfg)
                            btn1_tap_times = []
                            set_leds(1, 1, 1)
                            time.sleep(0.5)
                            all_leds_off()

                    # Nur Starten, wenn wirklich NUR DIESER EINE Knopf gedrückt ist
                    if not is_busy and states[(i+1) % 3] == 1 and states[(i+2) % 3] == 1:
                        recipe = next((r for r in cfg['recipes'] if r['id'] == i + 1), None)
                        if recipe:
                            run_recipe_async(recipe['pumpA'], recipe['pumpB'], leds[i])

                last_states[i] = state

        time.sleep(0.05)

_thread.start_new_thread(start_server, ())
poll_buttons()

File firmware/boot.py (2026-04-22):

import network
import time

# --- KONFIGURATION DEINES BOT-WLANS ---
AP_SSID = "GetraenkeBot_3000"  # So heißt das WLAN, das du am Handy siehst
AP_PASS = "party1234"          # Das Passwort (MUSS mindestens 8 Zeichen lang sein!)

def create_hotspot():
    print("Starte Getränke-Bot Hotspot...")
    # Access Point Interface (AP) aktivieren
    ap = network.WLAN(network.AP_IF)
    # Zuerst aktivieren, dann konfigurieren (wichtig bei manchen ESP32 Versionen)
    ap.active(True)
    ap.config(essid=AP_SSID, password=AP_PASS)
    # Kurz warten, bis das Netzwerk steht
    time.sleep(1)
    print("\n✅ Eigener Hotspot ist ONLINE!")
    print(f"📡 Finde dieses WLAN am Handy/Laptop: {AP_SSID}")
    print(f"🔑 Das Passwort ist: {AP_PASS}")
    # Die IP-Adresse auslesen (ist beim ESP32 als Hotspot fast immer 192.168.4.1)
    ip_adresse = ap.ifconfig()[0]
    print(f"🌐 Die IP-Adresse des Bots ist: {ip_adresse}")

# Starten
create_hotspot()

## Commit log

2026-02-20 MeilensteinAnalyse 20.2
    [Meilensteintrendanalyse_Getraenkemischer.xlsx]
2026-09-28 Firmware: LED-Blinken ohne Threads (non-blocking im Pumpen-Loop)
